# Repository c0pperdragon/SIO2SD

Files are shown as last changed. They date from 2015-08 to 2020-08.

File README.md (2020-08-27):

# SIO2SD
An Arduino-based floppy drive emulator for the Atari 8 bit computers.

This small Arduino build emulates an Atari 1050 floppy drive to connect
to an original Atari 8-bit computer. The program is compatible with
most Arduino boards. And for boards based on the Atmega32u4 it also provides
various log messages on the serial monitor to help debugging (mainly for my own use).

For a breadboard setup like my development device, you will need two push buttons,
two 7-digit LEDs and one SDCard socket (with built-in or separate level shifters) and
some wires and resistors. The connectivity is pretty standard and you will find
the details as comments in the source code.

For a more polished product, I have designed a PCB that can fit into a 3D-printed
case that resembles a tiny floppy drive with the SD card acting as a tiny floppy disk.

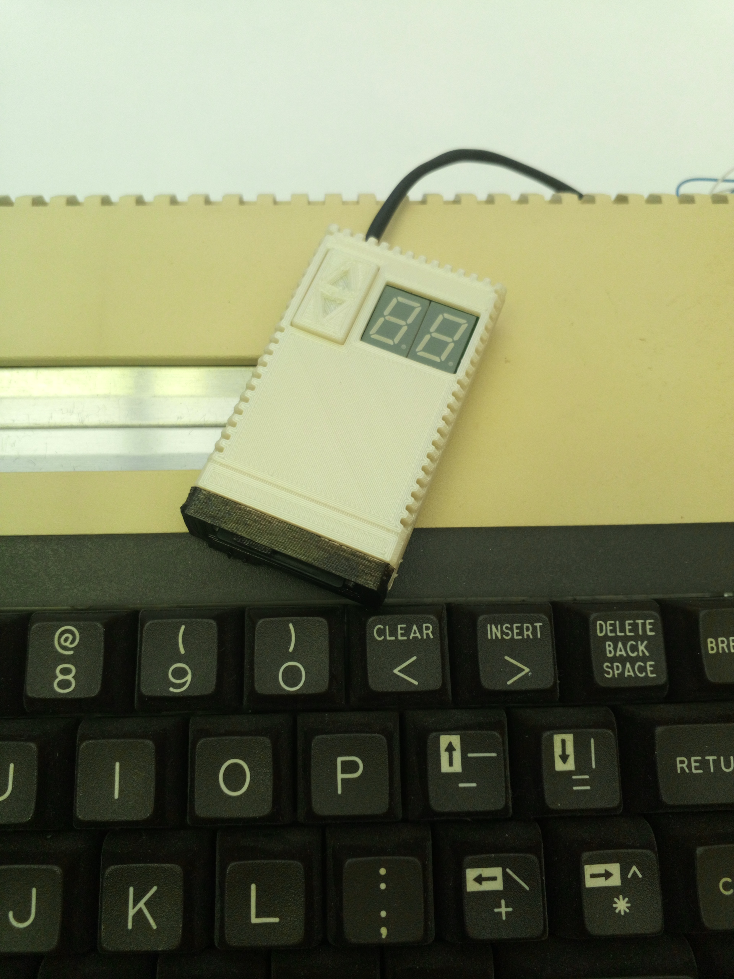
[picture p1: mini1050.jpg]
Big computer, small floppy drive


## Emulated floppies on SDcard
The floppy drive emulator needs an SDcard containing .ats files for each individual floppy disk.
Because there is no elaborated user-interface on the device, the naming and location of the files
need to follow a fixed system: The files are searched for in a directory ATARI/
on the root of the SDcard. Every disk file must be named nn_Anything.ats with two leading digits that correspond to the
numeric display on the device and the mandatory '_' character. Alternatively you can also
have a folder named nn_Anything with individual files inside. Such a folder will be emulated
as an read-only enhanced density floppy containing these files.

Currently only a very basic support for single density (720 sectors)
and enhanced density (1040 sectors) floppies is provided without special functions for any third-party devices.

## User interface
You can switch though the numbered disks 00 to 99 with the two buttons. This is the maximum number of disks 
supported on a single SDcard. When you switch beyond 99, you will see -- on the display, which means the device
now emulates a switched off floppy drive. Selecting a number for which no diskfile exists will simulate 
a device with no floppy inserted (in this case you can create a diskfile with the DOS format functions).

You can also emulate a second floppy drive, which is very usable for example for holding the save disks
for games that support this. To do so, you need to press both buttons to make the small indicator dot appear
on the left LCD block. This means that the number you see in the display is the floppy that is inserted
in drive 2. This floppy can now also be changed with the two buttons. It is even possible to select the same 
floppy in both drives at once (but this is probably of no great use).

## Latest hardware

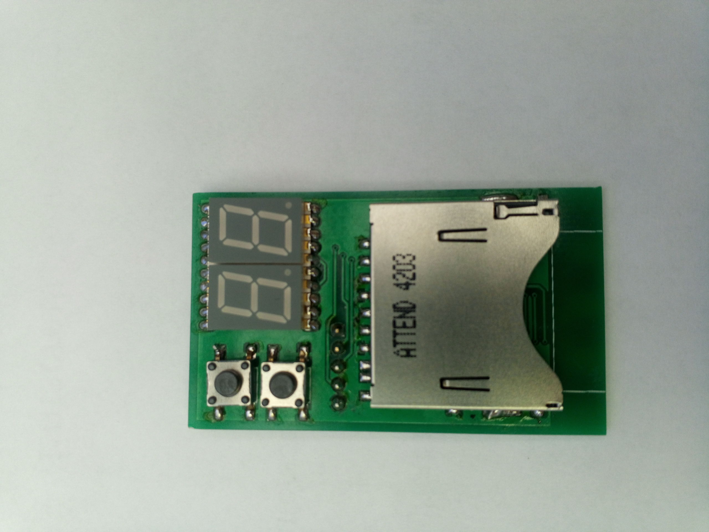
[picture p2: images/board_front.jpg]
Front side

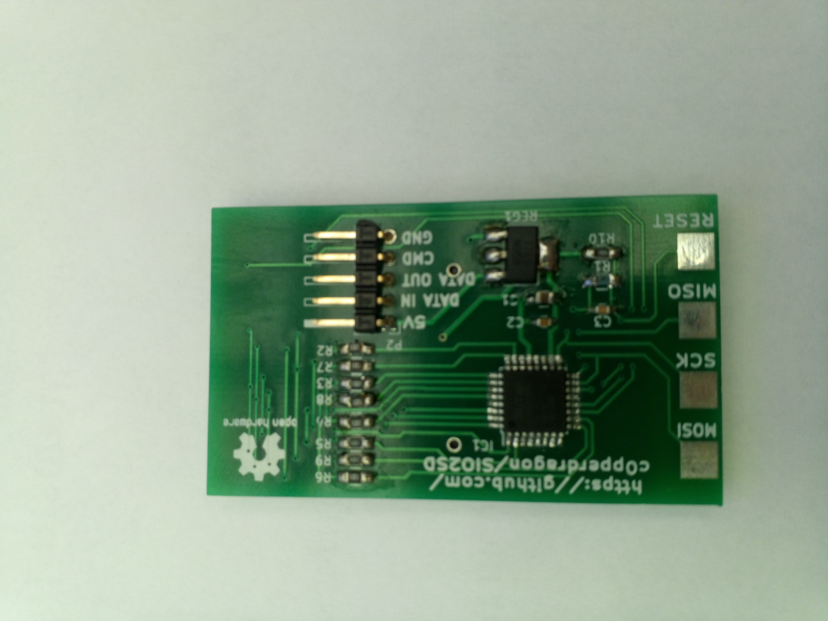
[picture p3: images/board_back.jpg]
Back side


## 3D-printed case

My brother went to greate lengths, designing a proper case for the floppy emulator. 
In my oppinion, this now looks absolutely phantastic.  

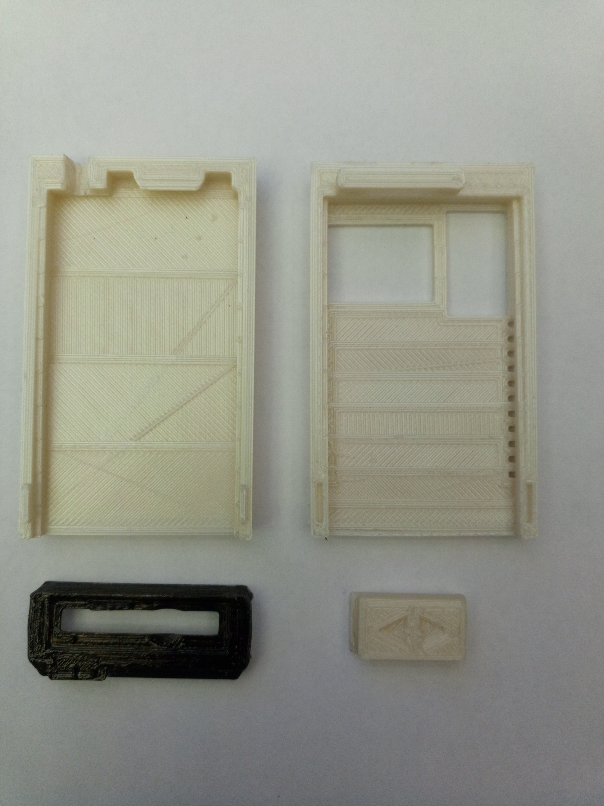
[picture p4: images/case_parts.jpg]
Individual parts of the case

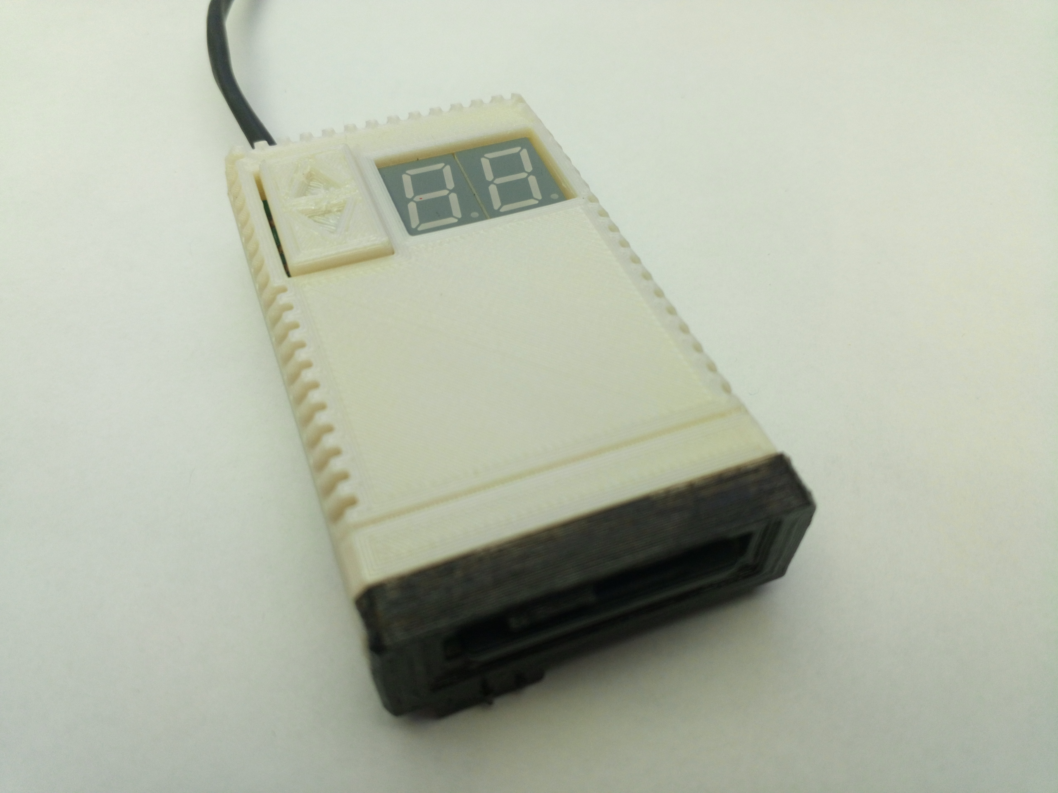
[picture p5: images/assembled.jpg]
Completely assembled


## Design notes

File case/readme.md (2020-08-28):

# Housing for an SD-Card version of the popular Atari-1050 floppy drive.

The case consists of 4 pieces and can be assembled without any screws.
It was modelled with blender, exported to STL files and sliced with cura.

The generated gcode is optimized for the anycubic i3-mega printer.

Layerheight is 0.2, first layer was 0.15 anyway because i wanted to avoid too much elephant foot, for otherwise the important design parts may be lost.

List of files:
* atari1050_sd_final.blend   - Blender file with the original Model data
* atari1050_sd_drive.gcode   - gcode for the 3d printer

* hull_top.stl, 
* hull_bottom.stl, 
* frontplate.stl, 
* buttons.stl                - STL-Files of the 4 Parts

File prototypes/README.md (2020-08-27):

# Prototype hardware variants

* First prototype with Arduino Micro. 
This was hand-wired. No longer supported by the firmware.

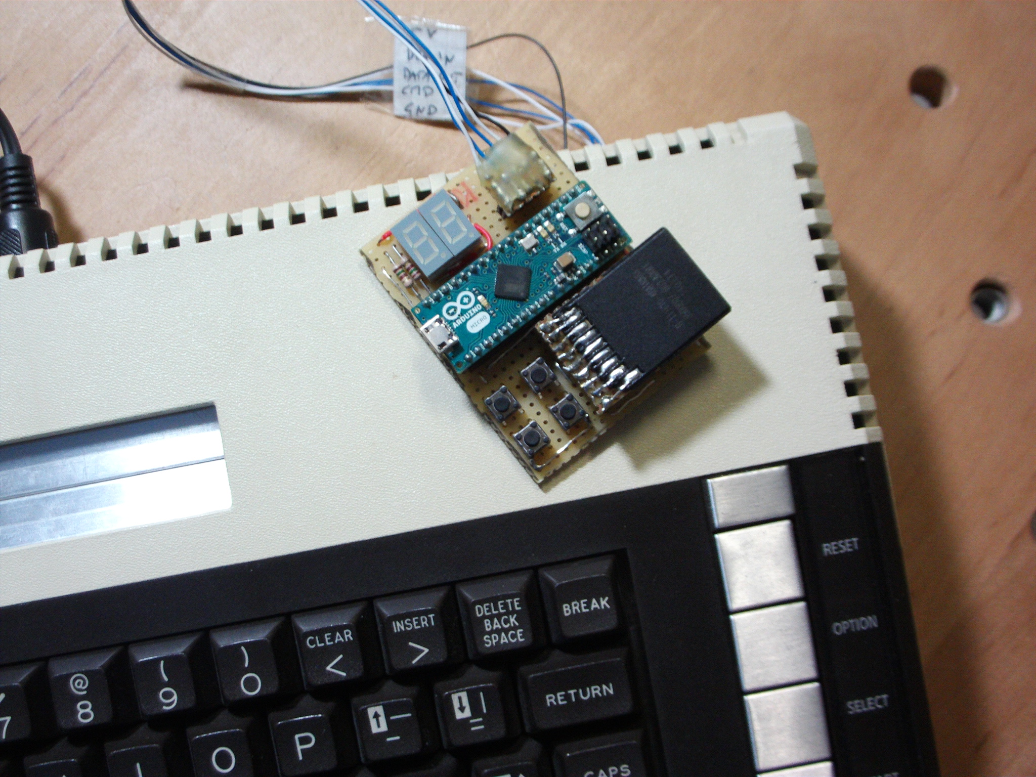
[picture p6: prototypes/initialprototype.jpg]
Initial Prototype


* Breadboard setup with Arduino Micro.
Because the MCU is running with 5V, I need level shifters to interface with the SDCard. This setup directly drives the 
Data-In line of the Atari without considering a multiple-slave configuration. This could be corrected with a simple schottky diode.
To keep the part count down, this setup only uses a single resistor per LED digit which causes varying brightness of the display segments.

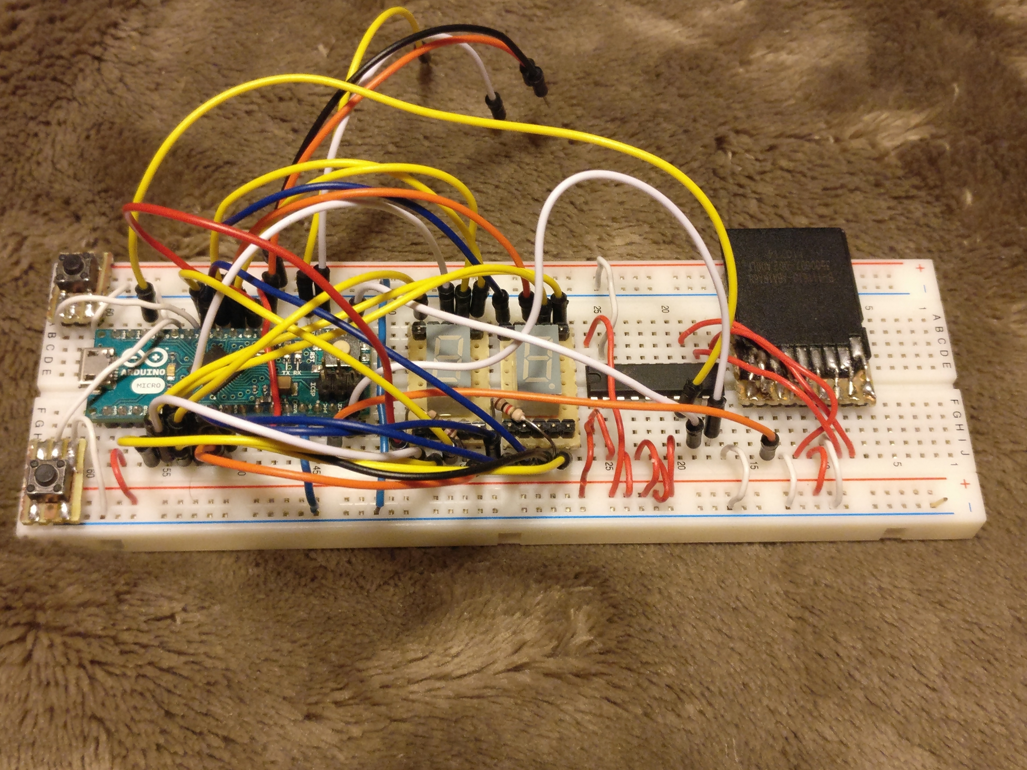
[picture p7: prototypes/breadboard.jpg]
Breadboard


* Bare bone ATmega328 (DIP package).
Designed to fit into a small form factor by using a home-etched two board design.
The MCU is running at 8MHz on 3.3V and can talk to SDCard without level shifters. The logic level difference between Atari and 
the MCU causes the incoming SIO high levels to be pulled down to about 3.9V by the internal clamp diodes. This only creates 
a small current (0.2mA) and should be OK as long as these lines are only driven by the pull-up resistors of the Atari.
The LEDs have resistors on the digit select lines only, therefore the brightness varies with the pattern.

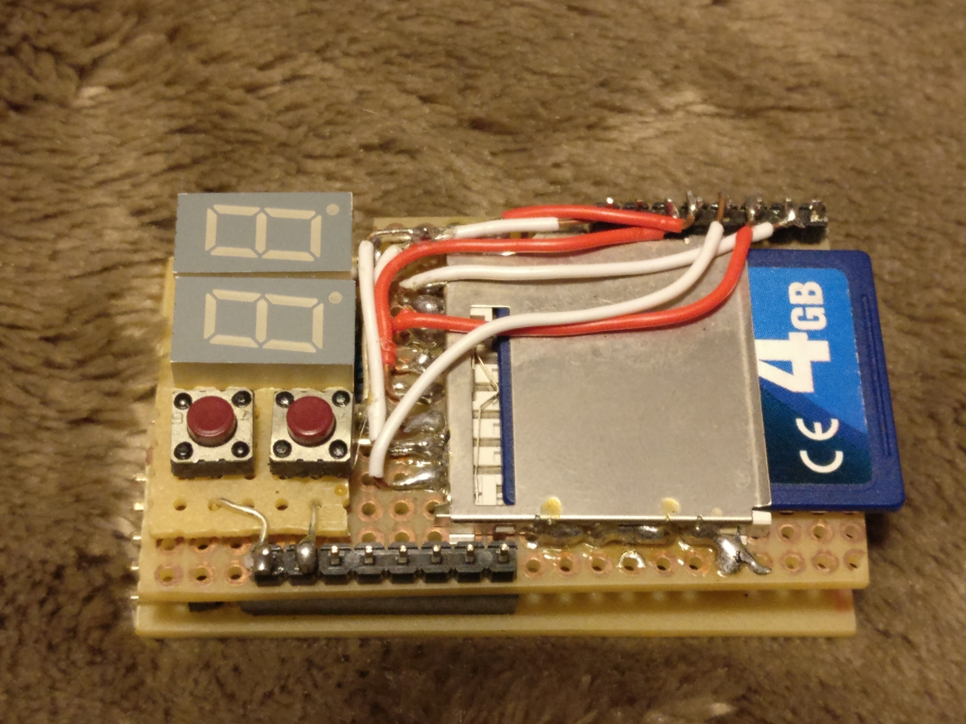
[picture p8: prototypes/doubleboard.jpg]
Double PCB layout


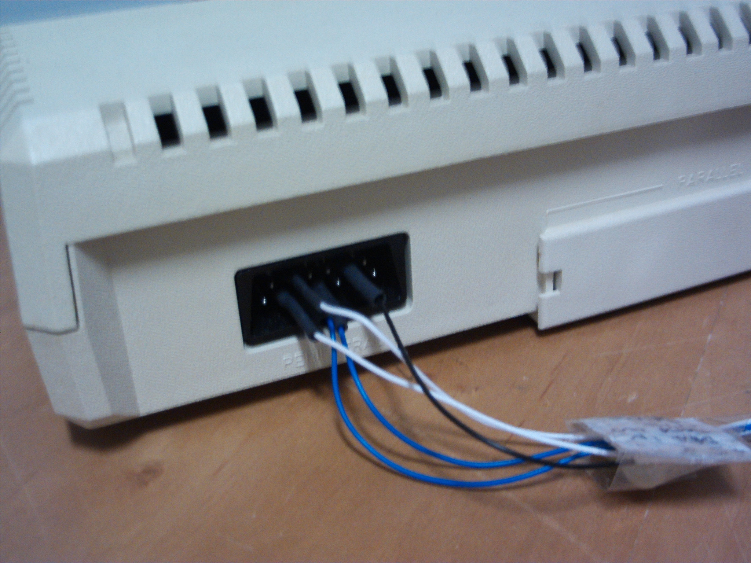
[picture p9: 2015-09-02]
doc/plugs.jpg

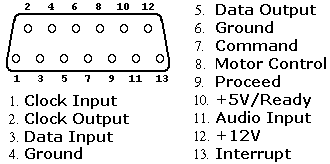
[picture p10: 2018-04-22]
doc/sio_socket.gif

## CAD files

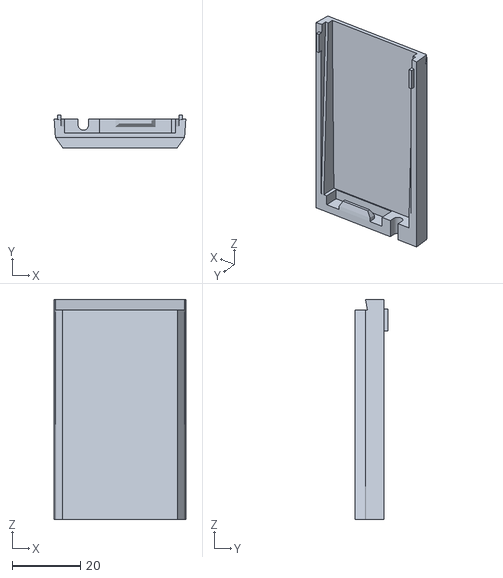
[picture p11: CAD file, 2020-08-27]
case/hull_bottom.stl
38.5 x 9.52 x 64.3

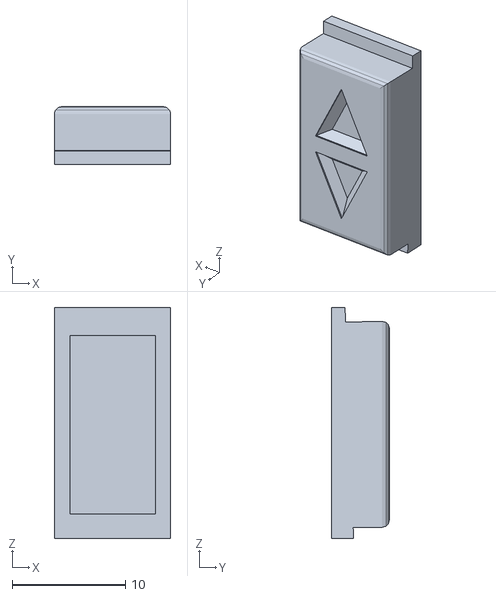
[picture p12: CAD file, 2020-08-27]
case/buttons.stl
10.3 x 5.13 x 20.4

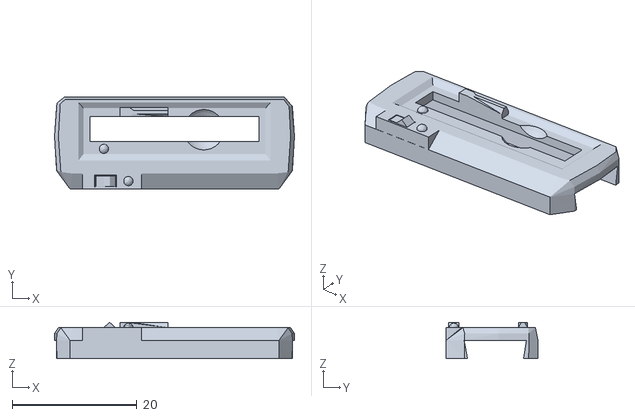
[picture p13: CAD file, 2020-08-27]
case/frontplate.stl
38.5 x 14.8 x 5.79

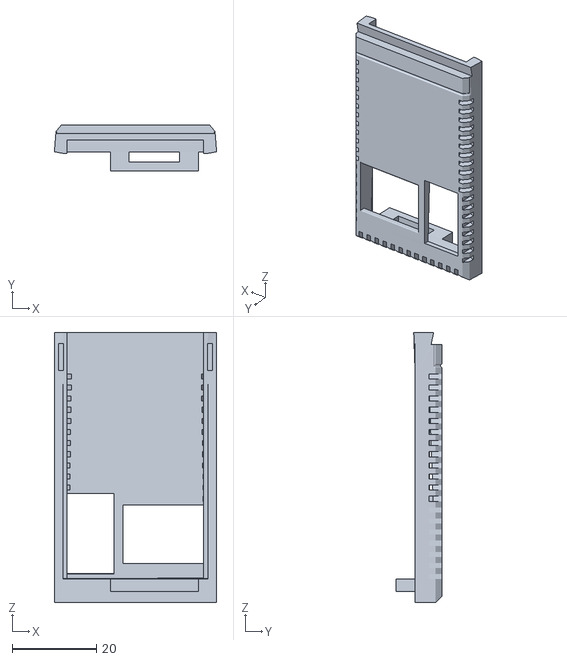
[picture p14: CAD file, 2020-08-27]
case/hull_top.stl
38.5 x 10.8 x 64.1

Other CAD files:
case/atari1050_sd_final.blend

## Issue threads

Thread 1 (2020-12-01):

No component type designation for D1

hanshuebner, 2020-12-01:
Thanks for making your SIO2SD available.  I built it and it looks gorgeous!

I have tried an 1N4148 for D1 as there is no type designation for it in the BOM, and the board does not react to commands on the SIO bus.  Does this diode need to be a Schottky diode?  If so, can you let me know what kind of diode works best?

Thanks!  Hans

c0pperdragon, 2020-12-01:
Yes, it needs to be a schottky diode with a forward voltage as low as possible. You may even shorten this connection when using the SIO2SD as the only device on the SIO bus (for test purposes). With multiple devices the diode is mandatory.

hanshuebner, 2020-12-01:
Thanks!  I'll try to find a suitable type, but if you could recommend one, it'd be greatly appreciated!  Cheers!

Closed 2020-12-01.

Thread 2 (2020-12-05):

Fuse bit settings not documented

hanshuebner, 2020-12-05:
Sorry to bother again:  Can you share the correct fuse bit settings for the device?

c0pperdragon, 2020-12-06:
I did not make special requirements in this regard to make the software work with any arduino compatible device.

When I designed my board, I could not get an Atmega328P, but only the slightly different Atmega328PB in the necessary package size. This gave me a bit of extra trouble because the chip ID is different and the flashing software did not work. I can not remember how I overcame this problem, but in the end it worked somehow.
By using the "normal" Atmega328P this should be easier as there is very good support in the arduino system for such bar-bones setups.
https://www.arduino.cc/en/Tutorial/BuiltInExamples/ArduinoToBreadboard
You need configure it to use the internal oscillator at 8Mhz.

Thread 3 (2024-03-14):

does it not run on normal Arduino Uno with 16MHz ?

mega-hz, 2024-03-14:
Hi,

is it right that this doesn't run on 16MHz?
If so, could you please correct the timers for running on staandart 16MHz?

c0pperdragon, 2024-03-14:
I don't think you need to change anything with the timings and run with 16MHz just fine. The timings are normally adjusted by the Arduino libraries accordingly.
8 MHz was just the highes speed available on a bare chip without external oscillator.

mega-hz, 2024-03-14:
ah, ok.
would it be possible to remove sd part and just listen to sio devices and commands?
Say, if D1 is reading, turn on a led, if writing, turn on another led....

c0pperdragon, 2024-03-14:
Brobably, but for this kind of bus-sniffing, the current code is a real overkill.
Maybe you want to do you own research on how to program such a thing from scratch. Here is a good resource for the protocol details:
https://www.atarimax.com/jindroush.atari.org/asio.html

mega-hz, 2024-03-14:
yes i know this site. just thought why do the whole work again. Your Sio Part should be run only, i will try.

mega-hz, 2024-03-14:
but stilll a nice project!
Even i prefere an display instead of 7Seg.

mega-hz, 2024-03-15:
i've got it running!
I only need your "handle-sio" routine.
If you don't mind i would like to use this in another Device.
SIO Device,Commands are shown on a LCD, works great!

c0pperdragon, 2024-03-15:
very nice.
and sure, use the code wherever you like

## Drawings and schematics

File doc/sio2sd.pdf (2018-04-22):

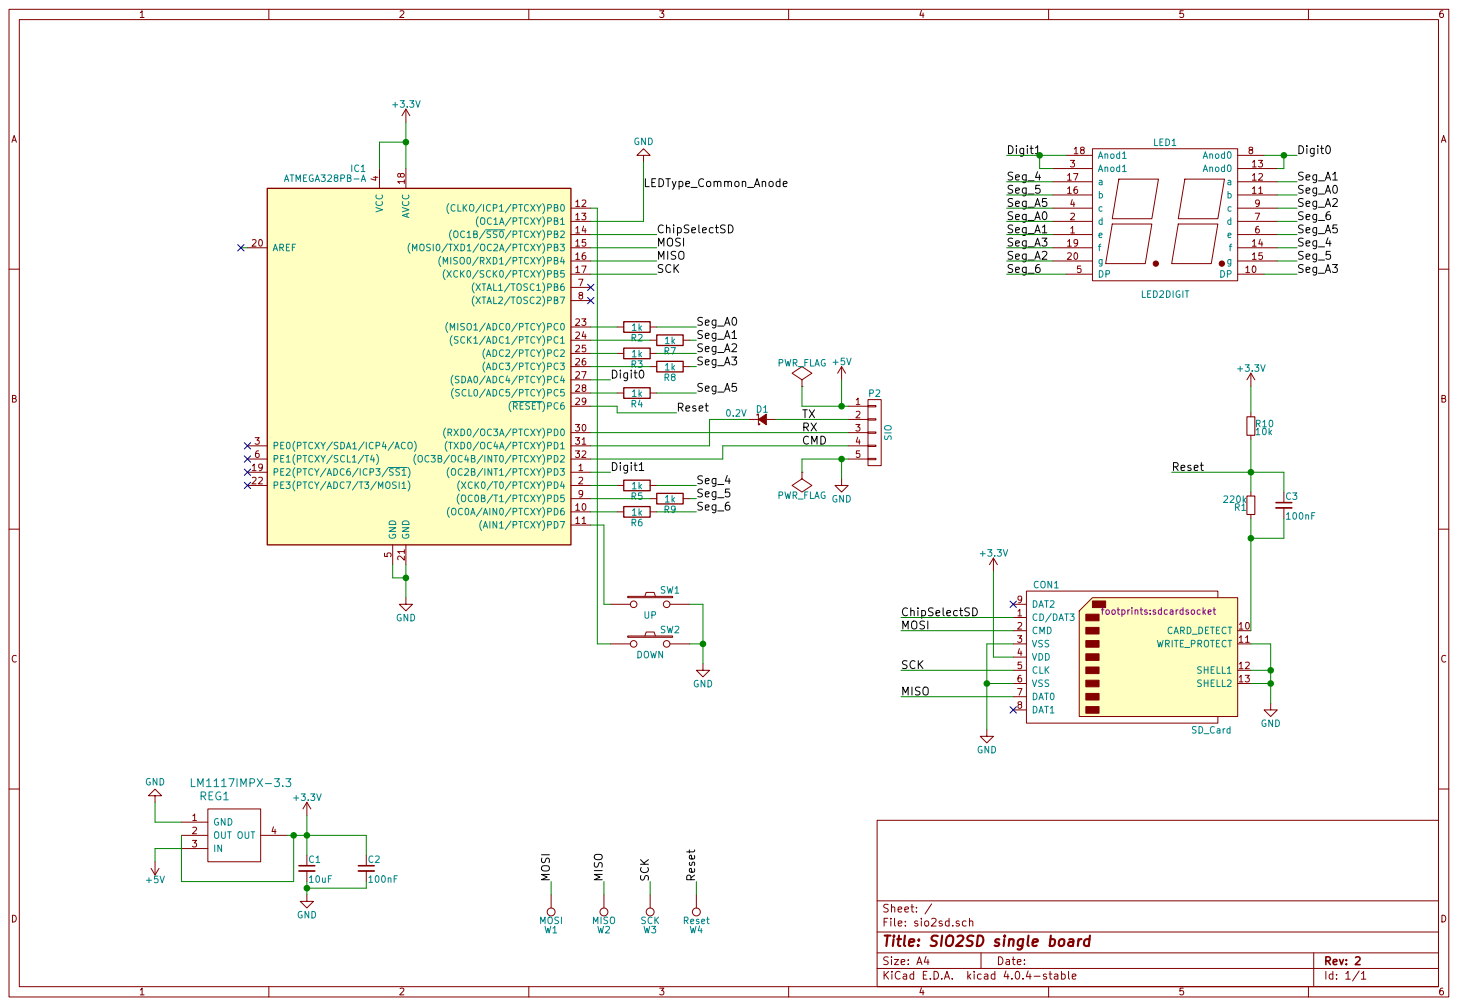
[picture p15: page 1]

File: sio2sd.sch Sheet: /
Id: 1/1 Title: SIO2SD single board

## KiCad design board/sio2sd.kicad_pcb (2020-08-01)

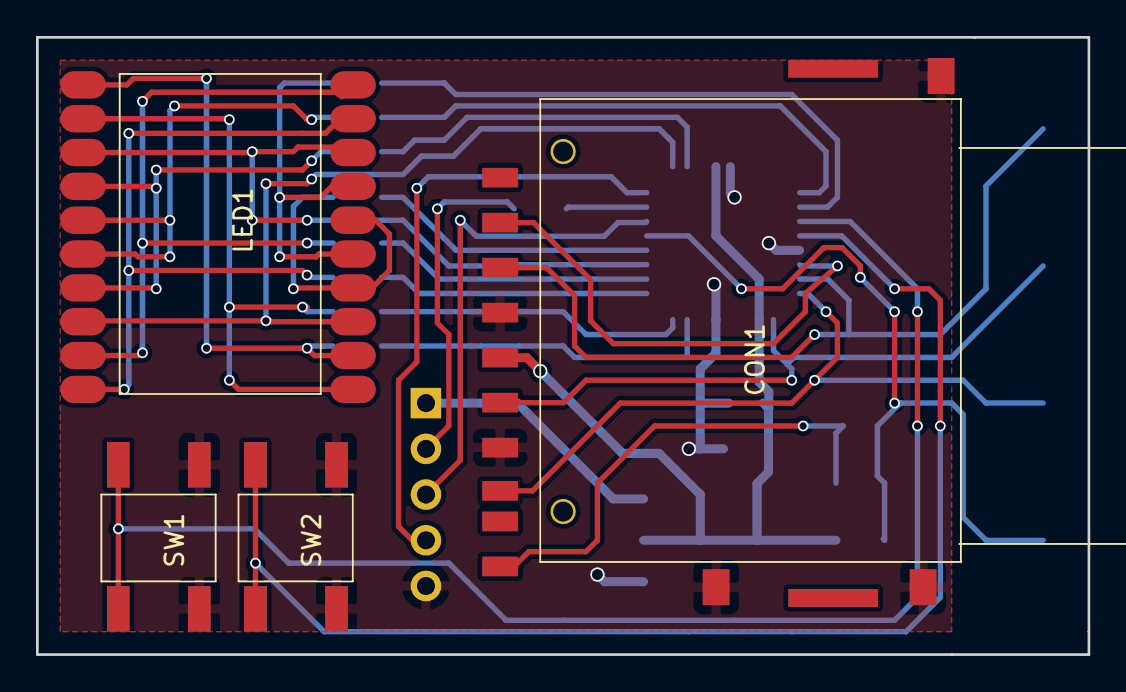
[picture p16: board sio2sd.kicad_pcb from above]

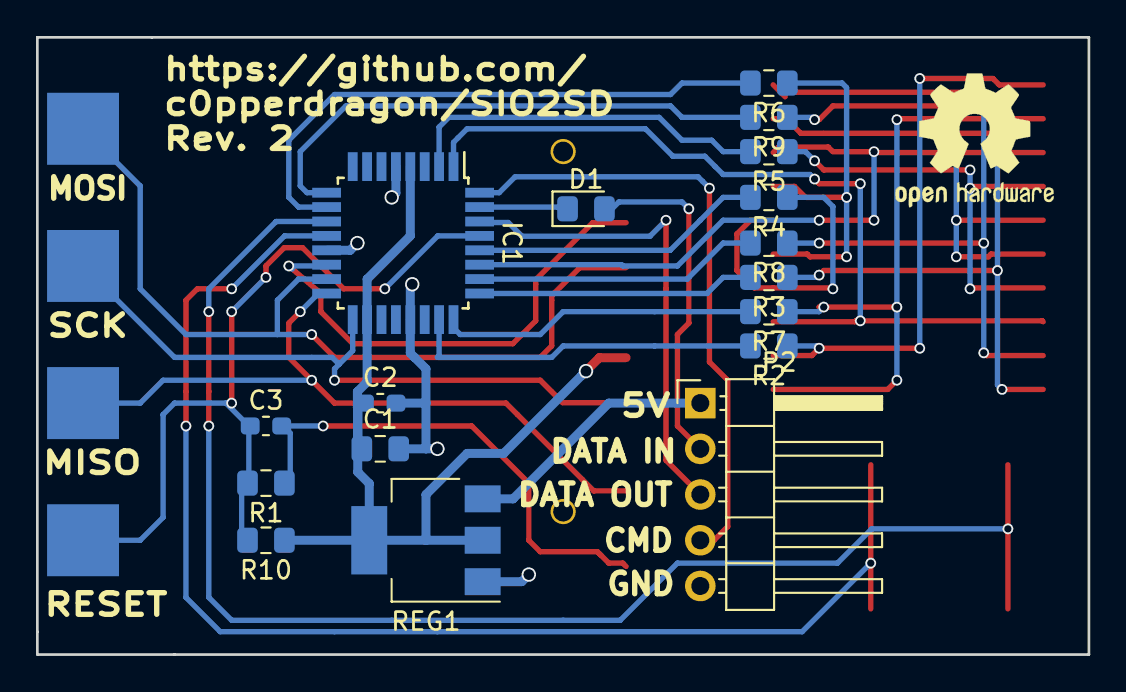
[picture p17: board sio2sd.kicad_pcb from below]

Board: 2 copper layers, 58.4 x 34.3 mm, 25 parts (21 on the bottom side), 33 nets.

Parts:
C1: 10uF; C_0805_2012Metric_Pad1.15x1.40mm_HandSolder
C2, C3: 100nF; C_0603_1608Metric_Pad1.05x0.95mm_HandSolder
CON1: SD_Card; sdcardsocket
D1: 0.2V; D_0805_2012Metric_Pad1.15x1.40mm_HandSolder
IC1: ATMEGA328PB-A; TQFP-32_7x7mm_P0.8mm
LED1: LED2DIGIT; led2digit
P2: SIO; PinHeader_1x05_P2.54mm_Horizontal
R1: 220k; R_0805_2012Metric_Pad1.15x1.40mm_HandSolder
R2, R3, R4, R5, R6, R7, R8, R9: 1k; R_0805_2012Metric_Pad1.15x1.40mm_HandSolder
R10: 10k; R_0805_2012Metric_Pad1.15x1.40mm_HandSolder
REG1: LM1117IMPX-3.3; SOT-223
SW1: UP; button
SW2: DOWN; button
W1: MOSI; pad
W2: MISO; pad
W3: SCK; pad
W4: Reset; pad

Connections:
+3V3: C1.1, C2.1, CON1.4, IC1.4, IC1.18, R10.1, REG1.2, REG1.4
+5V: P2.1, REG1.3
/CMD: IC1.32, P2.4
/ChipSelectSD: CON1.1, IC1.14
/Digit0: IC1.27, LED1.8, LED1.13
/Digit1: IC1.1, LED1.3, LED1.18
/MISO: CON1.7, IC1.16, W2.1
/MOSI: CON1.2, IC1.15, W1.1
/RX: IC1.30, P2.3
/Reset: C3.1, IC1.29, R1.2, R10.2, W4.1
/SCK: CON1.5, IC1.17, W3.1
/Seg_4: LED1.14, LED1.17, R5.1
/Seg_5: LED1.15, LED1.16, R9.1
/Seg_6: LED1.5, LED1.7, R6.1
/Seg_A0: LED1.2, LED1.11, R2.1
/Seg_A1: LED1.1, LED1.12, R7.1
/Seg_A2: LED1.9, LED1.20, R3.1
/Seg_A3: LED1.10, LED1.19, R8.1
/Seg_A5: LED1.4, LED1.6, R4.1
/TX: D1.2, P2.2
GND: C1.2, C2.2, CON1.3, CON1.6, CON1.11, CON1.12, CON1.13, IC1.5, IC1.13, IC1.21, P2.5, REG1.1, SW1.2, SW2.2
unnamed: C3.2, CON1.10, R1.1
unnamed: D1.1, IC1.31
unnamed: IC1.2, R5.2
unnamed: IC1.9, R9.2
unnamed: IC1.10, R6.2
unnamed: IC1.11, SW1.1
unnamed: IC1.12, SW2.1
unnamed: IC1.23, R2.2
unnamed: IC1.24, R7.2
unnamed: IC1.25, R3.2
unnamed: IC1.26, R8.2
unnamed: IC1.28, R4.2

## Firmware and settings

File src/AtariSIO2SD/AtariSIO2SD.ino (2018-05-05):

// --------- Program code for the IOS2SD Atari 1050 disk drive emulator -----------
// The program should be compatible with most arduino boards, as well
// as with a bare-bone atmega mcu.
// On boards with the ATmega32U4, logging via the usb uplink is enabled,
// while the the serial communication to the SIO interface 
// is routed over the dedicated serial pins. 

#include <SPI.h>
#include <SD.h>
#include <EEPROM.h>

// serial port RX/TX to Atari is either Serial or Serial1, d
// and if available, use USB line for logging
#if defined(__AVR_ATmega32U4__)
    #define SIO Serial1
    #define PRINT Serial.print
    #define PRINTLN Serial.println
    #define PRINTBEGIN Serial.begin
#else
    #define SIO Serial
    #define PRINT(...)        1
    #define PRINTLN(...)      1
    #define PRINTBEGIN(...)   1
//    #include <SoftwareSerial.h>
//    SoftwareSerial Logger(A7, 13); // RX, TX
//    #define PRINT Logger.print  // (...)        1
//    #define PRINTLN Logger.println   // (...)      1
//    #define PRINTBEGIN Logger.begin  // (...)   1
#endif

// ------------------------ the wiring up of all components ------------------------
// -- connection to Atari SIO port
                              // default arduino RX -> serial data from Atari SIO pin 5
                              // default arduino TX -> serial data to Atari SIO pin 3
#define PIN_SIOCOMMAND  2     //                    -> CMD signal from Atari SIO pin 7

// -- connection to SDCARD
                              // default MOSI
                              // default MSIO
                              // default SCK
#define PIN_CHIPSELECT  10    // enables SDCARD on SPI bus

// -- connection to LED display and mode selector
#define PIN_DIGIT0 A4         // enables LED digit 0 (right digit)
#define PIN_DIGIT1 3          // enables LED digit 1 (left digit)
// the digit segments are differently assigned for digit 0 and 1  
//           segment:    a   b   c   d   e   f   g   DP
byte pin_segments0[8] = {A1, A0, A2, 6,  A5, 4,  5,  A3}; 
byte pin_segments1[8] = {4,  5,  A5, A0, A1, A3, A2, 6};  
#define COMMON_ANODE_SELECTOR 9  // pull this input low to select common annode LED 

// -- connection to input buttons
#define PIN_BUTTON0  7      // up button   (connects to GND)
#define PIN_BUTTON1  8      // down button (connects to GND)


// ------------------ DISK SELECTOR (LED DIGITS AND BUTTONS) -----------
// because the two digits are displayed in a multiplexted fashion (to reduce number of needed pins),
// they will be displayed alternately. a timer interrupt  comes handy to do this.

volatile byte selecteddisk[2];
volatile int activitylight[2];
#define ACTIVITY_LIGHT_DURATION 10

byte activedigit; 
byte showndiskdrive;
int valuesavedelay;

byte prevbuttonstate;
byte timesincebuttonchange;
bool inputlock;
bool showerror;

// various digits             gfedcba
byte digitpatterns[13] = 
{   B00111111,   // 0
    B00000110,   // 1
    B01011011,   // 2
    B01001111,   // 3
    B01100110,   // 4
    B01101101,   // 5
    B01111101,   // 6
    B00000111,   // 7
    B01111111,   // 8
    B01101111,   // 9
    B01000000,   // -
    B01111001,   // E
    B01010000,   // r
};

#define TIMERFREQUENCY ((F_CPU/2)/256)      // timer frequency after prescaling of 256 (in Hz)
#define TIMERCYCLES  (TIMERFREQUENCY/200)   // this many timer ticks to get a 200Hz interrupt period
#define TIMERRESETVALUE (65536-TIMERCYCLES) // set counter to overflow in given time

void initdiskselector()
{
    byte i;

    // init input buttons
    pinMode(PIN_BUTTON0, INPUT_PULLUP);
    pinMode(PIN_BUTTON1, INPUT_PULLUP);
    pinMode(COMMON_ANODE_SELECTOR, INPUT_PULLUP);
    
    // read selector values at startup
    selecteddisk[0] = read_eeprom(0);
    selecteddisk[1] = read_eeprom(1);
  
    // init various UI flags
    activitylight[0] = 0;
    activitylight[1] = 0;
    activedigit = 0;
    showndiskdrive = 0;
    valuesavedelay = 0;
    prevbuttonstate = 0;
    timesincebuttonchange = 0;
    inputlock = false;
  
    // configure and turn of digit selectors 
    pinMode(PIN_DIGIT0, OUTPUT);
    digitalWrite (PIN_DIGIT0, LOW);
    pinMode(PIN_DIGIT1, OUTPUT);
    digitalWrite (PIN_DIGIT1, LOW);  
    // configure and turn off individual digits
    for (i=0; i<8; i++)
    {   pinMode(pin_segments0[i], OUTPUT);
        digitalWrite (pin_segments0[i], LOW);
        pinMode(pin_segments1[i], OUTPUT);
        digitalWrite (pin_segments1[i], LOW);
    }  

    // start timer
    noInterrupts();  
    TCCR1A = 0;
    TCCR1B = 0;
    TCNT1 = TIMERRESETVALUE;  // Timer nach obiger Rechnung vorbelegen
    TCCR1B |= (1 << CS12);    // 256 als Prescale-Wert spezifizieren
    TIMSK1 |= (1 << TOIE1);   // Timer Overflow Interrupt aktivieren
    interrupts();              // alle Interrupts scharf schalten
}


// interrupt service routine is called 200 times per second 
// (must not take much time)
// this handles user input and also drives the LED digits
ISR(TIMER1_OVF_vect)        
{
  TCNT1 = TIMERRESETVALUE; 
  polldiskselector();
}
void polldiskselector()   
{
    // poll buttons only 100 times per second to reduce bumping
    if (activedigit==0 && !showerror) 
    {   byte buttonstate = 0;
    
        // --- query current button states and detect changes ---
        if (digitalRead(PIN_BUTTON0)==LOW) { buttonstate =  buttonstate | 1; }
        if (digitalRead(PIN_BUTTON1)==LOW) { buttonstate =  buttonstate | 2; }
    
        // -- detect a press of both buttons: switch shown disk drive 
        if ((buttonstate&3)==3 && (prevbuttonstate&3)!=3 && !inputlock)
        {   showndiskdrive = 1-showndiskdrive;
            inputlock = true;
        }
        if (prevbuttonstate==0 && buttonstate==0) { inputlock=false; }
    
        // -- detect clicks of single up and down buttons and provide key repeat function
        if (!inputlock)
        {   if ( ((buttonstate&1)==0 && (prevbuttonstate&1)!=0) || ((buttonstate&1)!=0 && timesincebuttonchange>=100) ) 
            {   selecteddisk[showndiskdrive] ++;
                if (selecteddisk[showndiskdrive]>100) selecteddisk[showndiskdrive]=0;  
                valuesavedelay = 100;    
            }
            if ( ((buttonstate&2)==0 && (prevbuttonstate&2)!=0) || ((buttonstate&2)!=0 && timesincebuttonchange>=100) ) 
            {   selecteddisk[showndiskdrive] --;
                if (selecteddisk[showndiskdrive]>100) selecteddisk[showndiskdrive]=100;      
                valuesavedelay = 100;    
            }
        }    
    
        // -- memorize current button state for next poll to then detect edges
        if (buttonstate!=prevbuttonstate)
        {   prevbuttonstate = buttonstate;
            timesincebuttonchange=0;
        }          
        else
        {   if (timesincebuttonchange<100) { timesincebuttonchange++; }
            else                           { timesincebuttonchange-=5; }
        }
        
        // --- handling of delay before saving the current selected value
        if (valuesavedelay>0 && buttonstate==0)
        {   valuesavedelay --;
            if (valuesavedelay==0)
            {   store_eeprom(0, selecteddisk[0]);
                store_eeprom(1, selecteddisk[1]);
            }
        }
    }
    

    // --- count down activity light duration
    if (activitylight[0]>0) {   activitylight[0]--;  }
    if (activitylight[1]>0) {   activitylight[1]--;  }
  
    // --- display digits alternatingly ----
    // switch to other digit
    activedigit = 1-activedigit;

    // determine if need to drive a common cathode or common anode LED
    byte commoncathode = digitalRead(COMMON_ANODE_SELECTOR);
  
    // turn on/off digit segments as needed (pin assignment is quite arbitrary)
    if (activedigit==0) 
    {   byte value = selecteddisk[showndiskdrive];
        value = showerror ? 12 : ((value<=99) ? (value % 10) : 10);   // when drive is off: - 
        digitalWrite (PIN_DIGIT1, commoncathode ? HIGH : LOW);  // turn off digit 1
        byte i;
        byte v = digitpatterns[value];
        for (i=0; i<7; i++) 
        {   if (v&(1<<i)) { digitalWrite (pin_segments0[i], commoncathode ? HIGH : LOW); }
            else          { digitalWrite (pin_segments0[i], commoncathode ? LOW : HIGH); }
        }
        // this dot is used to see if drive 0 is visible and if activity on disk 0
        bool dot = showndiskdrive==0 && !showerror;
        if (activitylight[0]>0) { dot = !dot; }
        if (dot) { digitalWrite (pin_segments0[7], commoncathode ? HIGH : LOW); }
        else     { digitalWrite (pin_segments0[7], commoncathode ? LOW : HIGH); }
        digitalWrite (PIN_DIGIT0, commoncathode ? LOW : HIGH);  // turn on digit 0
    }
    else 
    {   byte value = selecteddisk[showndiskdrive];
        value = showerror ? 11 : ((value<=99) ? (value / 10) : 10);   // when drive is off: -
        digitalWrite (PIN_DIGIT0, commoncathode ? HIGH  : LOW);   // turn off digit 0
        byte i;
        byte v = digitpatterns[value];
        for (i=0; i<7; i++) 
        {   if (v&(1<<i)) { digitalWrite (pin_segments1[i], commoncathode ? HIGH : LOW); }
            else          { digitalWrite (pin_segments1[i], commoncathode ? LOW : HIGH); }
        }
        // this dot is used to see if drive 1 is visible and if activity on disk 1
        bool dot = showndiskdrive==1 && !showerror;
        if (activitylight[1]>0) { dot = !dot; }
        if (dot) { digitalWrite (pin_segments1[7], commoncathode ? HIGH : LOW); } 
        else     { digitalWrite (pin_segments1[7], commoncathode ? LOW : HIGH); } 
        digitalWrite (PIN_DIGIT1, commoncathode ? LOW : HIGH);  // turn on digit 1
    }  
}

// ------------------ EEPROM storage with wear-levelling -----------
// To prevent frequent writing to a single EEPROM cell to wear out this particual storage,
// the writes are distributed over a wide range of the available EEPROM. This is
// possible because only a very tiny amount of data needs to be stored int each slot
// (a 7-bit value).
// It works as follows: A splot consists of 256 bytes EEPROM storage. The one active
// data value (7 bits) can be found on the first byte position that has a different most significant
// bit (MSB) value than all previous bytes. In the case that all bytes in the slot have the
// same MSB, the very first byte is taken.
// Writing a new value into the slot will be done by overwriting the byte just before
// the previous value-carrying byte with the proper MSB set. 
// By this only one byte is overwritten in each write operation and it will always be a
// different one in the slot.

byte read_eeprom(byte slot)
{
    // find the first different MSB and take the value from there
    int start = ((int)slot) * 256;
    byte b0 = EEPROM.read(start);
    int i;
    for (i=start+1; i<start+256; i++)
    {   byte b1 = EEPROM.read(i);
        if ( (b0&0x80) != (b1&0x80)) { return b1 & 0x7f; }
        b0 = b1;
    }
    return EEPROM.read(start) & 0x7f;
}

void store_eeprom(byte slot, byte value)
{
    // make sure to not store unnecessarily 
    if (read_eeprom(slot)==value) { return; }

    // find the first different MSB 
    int start = ((int)slot) * 256;
    byte b0 = EEPROM.read(start);
    int i;
    for (i=start+1; i<start+256; i++)
    {   byte b1 = EEPROM.read(i);
        // if found a different MSB, store the value just in the place before
        if ( (b0&0x80) != (b1&0x80)) 
        {   EEPROM.write(i-1, (value&0x7f) | (b1&0x80));
            PRINT(F("Stored "));
            PRINT(value);
            PRINT(F(" to EEPROM byte "));
            PRINTLN(i-1);
            // when having written to location 0 make sure to have no other MSB edges 
            if (i==1) { cleanmsb_eeprom(slot); }
            return;
        }
        b0 = b1;
    }
    // if no suitable place could be found (all MSB equal, start at the end)
    EEPROM.write(start+255, (value&0x7f) | ((~b0)&0x80)); 
}

void cleanmsb_eeprom(byte slot)
{
    int start = ((int)slot) * 256;
    byte b0 = EEPROM.read(start);
    int i;
    for (i=start+1; i<start+256; i++)
    {   byte b1 = EEPROM.read(i);
        if ( (b0&0x80)!=(b1&0x80) )
        {   EEPROM.write(i, (b0&0x80)|(b1&0x7f)); 
            PRINT(F("Cleaned EEPROM byte "));
            PRINTLN(i);            
        }
    }
}



// ---------------------- DISK FILE HANDLING  -----------------------

boolean isinitsd = false;

File diskfile;                 // can be a .ATR file or a directory
unsigned int disksize;         // size in sectors

File atarifile;                // currently used file of a directory (if used in this mode)
unsigned int firstfilesector;  // first sector (numbered in "usable sectors) of the file
byte directoryindexoffile;     // to which directory entry the current file belongs


void opendiskfile(int index)
{  
    // check if desired file is already open - continue to use it
    if (diskfile && isrequesteddiskfile(diskfile,index)) { return; } 
  
    // before switching disk file, close any previous open
    if (diskfile) { diskfile.close(); }
    if (atarifile) { atarifile.close(); }

    // if not done already try to initialize the SDcard - on failure can not resume
    if (!isinitsd)
    {
        pinMode(PIN_CHIPSELECT,OUTPUT);
        digitalWrite(PIN_CHIPSELECT,HIGH);
        if (!SD.begin(PIN_CHIPSELECT)) 
        {   PRINTLN(F("SDCard failed, or not present"));
            return;
            showerror = true;
        }      
        isinitsd = true;
    }
  
    // try to scan the files in the ATARI directory on the SDCARD and 
    // locate the file name beginning with the correct index (2 digits).
    char fullname[60];
    fullname[0] = '\0';
  
    File root = SD.open(F("ATARI"));
    if (!root || !root.isDirectory())
    {   PRINTLN(F("Can not locate ATARI/ directory"));      
        return;             
    }  
    while (fullname[0]=='\0')
    {   File entry = root.openNextFile();
        if (!entry)
        {   PRINT(F("Could not find file for disk "));
            PRINTLN(index);
            root.close();
            return;
        }
        // check if name matches
        if (isrequesteddiskfile(entry,index))
        { // fill data into the fullname variable (which terminates the loop)
            strcat (fullname, "ATARI/");
            strcat (fullname, entry.name());
        }
        entry.close();
    }      
    root.close();
  
    // try to open the file in read-write mode, and if this does not
    // succeed in read-only mode
    PRINT(F("Trying to open "));
    PRINTLN(fullname);      

    bool readonly = false;
    diskfile = SD.open(fullname, FILE_WRITE);
    if (diskfile)
    {   diskfile.seek(0);
    }
    else
    {   diskfile = SD.open(fullname, FILE_READ);
        readonly = true;
    }  
    // abort if not possible to open
    if (!diskfile)
    {   PRINT(F("Can not open disk file"));
        PRINTLN(fullname);
        return;
    }       
    
    // check if the file is a directory instead of a diskfile 
    if (diskfile.isDirectory())
    {   PRINT(F("Using directory content to emulate a 1040 sector floppy: "));
        PRINTLN(fullname);
        disksize = 1040;
        return;
    }
    
    // read the header
    byte header[16];
    int didread = diskfile.read(header,16);
    if (didread!=16)
    {   PRINTLN(F("Can not read file header"));
        diskfile.close();
        return;
    }
    // check for signature and other settings
    if (header[0]!=0x96 || header[1]!=0x02)
    {   PRINTLN(F("Magic number not present"));
        diskfile.close();
        return;
    }
    if (header[5]!=0 or header[4]!=128)
    {   PRINTLN(F("Can only handle 128 byte sectors"));
        diskfile.close();     
        return;
     }

    unsigned long paragraphs = header[6];
    paragraphs = (paragraphs<<8) | header[3];
    paragraphs = (paragraphs<<8) | header[2];
    if (paragraphs<8 || paragraphs>0x70000)
    {   PRINTLN(F("Disk file size out of range."));
        diskfile.close();
        return;
    }
  
    // seems to be a valid diskfile - use it
    disksize = (paragraphs) >> 3;
    
    PRINT(F("SIZE: "));
    PRINT(disksize);
    PRINT(F(" sectors of 128 bytes"));
    if (readonly) { PRINTLN(F(" (read only)")); }
    else          { PRINTLN(F(" (writeable)")); }
}

bool isrequesteddiskfile(File f, int index)
{
    char* n = f.name();
    if (n[0]>='0' && n[0]<='9' && n[1]>='0' && n[1]<='9' && ((n[0]-'0')*10 + n[1]-'0')==index && n[2]=='_')
    {   return true; 
    }
    return false;
}

bool readsector(unsigned int sector, byte* data)
{   
    if (!diskfile || sector<1 || sector>disksize) { return false; }
    if (diskfile.isDirectory()) 
    {   if (!readsectorfromdirectory(sector,data)) { return false; }
        return true;
    }    
    if (!diskfile.seek(16+((unsigned long)(sector-1))*128) ) { return false; }
    return diskfile.read(data, 128) == 128;
}

bool writesector(unsigned int sector, byte* data)
{
    if (!diskfile || diskfile.isDirectory() || sector<1 || sector>disksize) { return false; }
    if (!diskfile.seek(16+((unsigned long)(sector-1))*128)) { return false; }
    return diskfile.write(data, 128) == 128;
}

bool diskavailable()
{
    if (diskfile) { return true; }
    else          { return false; }
}

bool creatediskfile(int index, int sectors)
{
    char fullname[101];
    fullname[0] = 0;
    strcat (fullname, "ATARI/");    
    
    opendiskfile(index);    
    // if possible reuse the already available disk file name (and remove old file first)
    if (diskfile)
    {   if (diskfile.isDirectory()) 
        {   PRINTLN(F("Can not format directory"));
            return false;
        }
        strcat (fullname, diskfile.name());
        diskfile.close();
        if (!SD.remove(fullname)) {
            PRINT(F("Can not remove old disk file "));
            PRINTLN(fullname);
            return false;
        }
    }
    // otherwise invent a new disk file name
    else
    {   strcat(fullname, "00_disk.atr");
        fullname[6] = '0' + (index / 10);
        fullname[7] = '0' + (index % 10);
    }

    PRINT(F("Creating disk file "));
    PRINT(fullname);
    PRINT(F(" with "));
    PRINT(sectors);
    PRINTLN(F(" sectors"));
    diskfile = SD.open(fullname, FILE_WRITE);
    if (!diskfile) { return false; }
    
    byte chunk[16];
    // construct header: magic number
    chunk[0] = (byte) 0x96;
    chunk[1] = (byte) 0x02;
    // paragraphs
    int paragraphs = sectors * 8; 
    chunk[2] = (byte) (paragraphs & 0xff);
    chunk[3] = (byte) ((paragraphs>>8) & 0xff);
    // sector size
    chunk[4] = (byte)128;
    chunk[5] = (byte)0;
    // 10 byte unused
    int i=0;
    for (i=6; i<16; i++) { chunk[i] = 0; }
    diskfile.write(chunk, 16);
    
    // create rest of file
    for (i=0; i<16; i++) { chunk[i] = 0x00; }
    for (i=0; i<paragraphs; i++)
    {   diskfile.write(chunk, 16);
    }

    diskfile.close();
    PRINTLN(F("Finished creating disk file"));
    return true;
}

const byte bootblocks[] PROGMEM = {
    0x00,0x03,0x00,0x07,0x40,0x15,0x4c,0x14,0x07,0x03,0x83,0x00,0xcc,0x19,0x01,0x04,
    0x00,0x7d,0xcb,0x07,0xac,0x0e,0x07,0xf0,0x35,0x20,0x5f,0x07,0xad,0x10,0x07,0xac,
    0x0f,0x07,0xa6,0x24,0x8e,0x04,0x03,0xa6,0x25,0x8e,0x05,0x03,0x18,0x20,0x6c,0x07,
    0x30,0x1c,0xac,0x11,0x07,0xb1,0x24,0x29,0x03,0xaa,0xc8,0x11,0x24,0xf0,0x11,0xb1,
    0x24,0x48,0xc8,0xb1,0x24,0x20,0x55,0x07,0x68,0xa8,0x8a,0x4c,0x22,0x07,0xa9,0xc0,
    0x0a,0xa8,0x60,0xa9,0x80,0x18,0x65,0x24,0x85,0x24,0x90,0x02,0xe6,0x25,0x60,0xad,
    0x12,0x07,0x85,0x24,0xad,0x13,0x07,0x85,0x25,0x60,0x00,0x00,0x8d,0x0b,0x03,0x8c,
    0x0a,0x03,0xa9,0x52,0xa0,0x40,0x90,0x04,0xa9,0x57,0xa0,0x80,0x08,0xa6,0x21,0xe0,
    0x08,0xd0,0x07,0x28,0x20,0x81,0x14,0x4c,0xb9,0x07,0x28,0x8d,0x02,0x03,0xa9,0x0f,
    0x8d,0x06,0x03,0x8c,0x17,0x13,0xa9,0x31,0x8d,0x00,0x03,0xa9,0x03,0x8d,0x09,0x13,
    0xa9,0x80,0x8d,0x08,0x03,0x0a,0x8d,0x09,0x03,0xad,0x17,0x13,0x8d,0x03,0x03,0x20,
    0x59,0xe4,0x10,0x05,0xce,0x09,0x13,0x10,0xf0,0xa6,0x49,0x98,0x60,0x20,0xad,0x11,
    0x20,0x64,0x0f,0x20,0x04,0x0d,0x4c,0xc7,0x12,0x00,0x00,0x64,0x08,0x8f,0x0a,0x4d,
    0x0a,0x8f,0x09,0xbc,0x07,0x2a,0x0b,0x80,0x40,0x20,0x10,0x08,0x04,0x02,0x01,0xff,
    0xad,0x0c,0x07,0x85,0x24,0xad,0x0d,0x07,0x85,0x25,0xad,0x0a,0x07,0x85,0x43,0xa2,
    0x07,0xa9,0x00,0x06,0x43,0x90,0x15,0xa0,0x05,0x91,0x24,0xa5,0x24,0x9d,0x29,0x13,
    0xa5,0x25,0x9d,0x31,0x13,0xa9,0x90,0x20,0x55,0x07,0xa9,0x64,0x9d,0x19,0x13,0xca,
    0x10,0xdf,0xa5,0x24,0x8d,0x39,0x13,0xa5,0x25,0x8d,0x3a,0x13,0xac,0x09,0x07,0xa2,
    0x00,0x88,0x98,0x9d,0x21,0x13,0x30,0x03,0x20,0x53,0x07,0xe8,0xe0,0x08,0xd0,0xf1,
    0xa5,0x24,0x8d,0xe7,0x02,0xa5,0x25,0x8d,0xe8,0x02,0xa9,0x00,0xa8,0x99,0x81,0x13,
    0xc8,0x10,0xfa,0xa8,0xb9,0x1a,0x03,0xf0,0x0c,0xc9,0x44,0xf0,0x08,0xc8,0xc8,0xc8,
    0xc0,0x1e,0xd0,0xf0,0x00,0xa9,0x44,0x99,0x1a,0x03,0xa9,0xcb,0x99,0x1b,0x03,0xa9,
    0x07,0x99,0x1c,0x03,0x60,0x20,0xad,0x11,0x20,0x7d,0x0e,0xbd,0x4a,0x03,0x9d,0x82,
    0x13,0x29,0x02,0xf0,0x03,0x4c,0x72,0x0d,0x20,0xec,0x0e,0x08,0xbd,0x82,0x13,0xc9      
};
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
void loop()
{
    handle_sio();
}

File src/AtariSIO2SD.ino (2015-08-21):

#include <SPI.h>
#include <SD.h>
#include <TimerOne.h>

#define PIN_CHIPSELECT  13
#define PIN_SIOCOMMAND  2


// ------------------ DISC SELECTOR (LED DIGITS AND BUTTONS) -----------
// because the two digits are displayed in a multiplexted fasion (to reduce number of needed pins),
// they will be displayed alternately. a timer interrupt  comes handy to do this.

byte prevbuttonstate[4];

volatile byte digit0value;  
volatile byte digit1value;  
volatile int activitylight;
byte activedigit; 

// various digits                0      1      2      3      4      5      6      7      8     9
bool segment_top[10]         = { true,  false, true,  true,  false, true,  true,  true,  true, true  };
bool segment_middle[10]      = { false, false, true,  true,  true,  true,  true,  false, true, true  };
bool segment_bottom[10]      = { true,  false, true,  true,  false, true,  true,  false, true, true  };
bool segment_lefttop[10]     = { true,  false, false, false, true,  true,  true,  false, true, true  };
bool segment_leftbottom[10]  = { true,  false, true,  false, false, false, true,  false, true, false };
bool segment_righttop[10]    = { true,  true,  true,  true,  true,  false, false, true,  true, true  };
bool segment_rightbottom[10] = { true,  true,  false, true,  true,  true,  true,  true,  true, true  };

void initdiscselector()
{
  int i;

  // init input buttons
  for (int i=0; i<4; i++)
  {   pinMode(A0+i, INPUT);
      prevbuttonstate[i] = HIGH;
  }
  
  // init visible digit values and toggle register
  digit0value = 0;
  digit1value = 0;
  activedigit = 0;
  activitylight = 0;
  
  // digit selectors are active high (turn off everything at begin)
  pinMode(11, OUTPUT);
  digitalWrite (11, LOW);
  pinMode(12, OUTPUT);
  digitalWrite (12, LOW);  
  // individual digit segments are active low (turn off everything at begin)
  for (i=3; i<=10; i++)
  {    
    pinMode(i, OUTPUT);
    digitalWrite (i, HIGH);
  }
  
  // start timer
  Timer1.initialize(5000);     // toggle with 100 Hz   
  Timer1.attachInterrupt(polldiscselector);    
}


int getdiskselectorvalue()
{
  return digit0value + digit1value*10;  
}

int setactivitylight()
{
    activitylight = 10;  
}

void polldiscselector()   // interrupt service routine (must not take much time)
{
  // --- query button changes ---
  int i;
  for (i=0; i<4; i++)
  {
      byte s = digitalRead(A0+i);
      if (s!=prevbuttonstate[i])
      {
        prevbuttonstate[i]=s;
        if (s==LOW)
        {   
            // modify digits without needing to do divisions (must be fast)
            switch (i)
            {  case 0: digit1value = digit1value<9 ? digit1value+1 : 0;
                       break;
               case 1: digit1value = digit1value>0 ? digit1value-1 : 9;
                       break;
               case 2: if (digit0value<9)
                       {  digit0value++;
                       }
                       else 
                       {  digit0value=0;
                          digit1value = digit1value<9 ? digit1value+1 : 0;
                       }
                       break;
               case 3: if (digit0value>0)
                       {  digit0value--;
                       }
                       else
                       {
                         digit0value = 9;
                         digit1value = digit1value>0 ? digit1value-1 : 9;
                       }
                       break;
            }
        }
      }
  } 

  // --- count down activity light duration
  if (activitylight>0)
  {
     activitylight--;
  }
  
  // --- display digits alternatingly ----
  // turn off previously active digit
  digitalWrite (11, LOW);
  digitalWrite (12, LOW);
  
  // switch to other digit
  activedigit = 1-activedigit;
  
  // turn on/off digit segments as needed (pin assignment is very arbitrary)
  if (activedigit==0)
  {
     byte v = digit0value;
     digitalWrite (3, segment_top[v] ? LOW : HIGH);
     digitalWrite (6, segment_middle[v] ? LOW : HIGH);
     digitalWrite (7, segment_bottom[v] ? LOW : HIGH);
     digitalWrite (5, segment_lefttop[v] ? LOW : HIGH);  
     digitalWrite (9, segment_leftbottom[v] ? LOW : HIGH);
     digitalWrite (10, segment_righttop[v] ? LOW : HIGH);  
     digitalWrite (8, segment_rightbottom[v] ? LOW : HIGH);
     digitalWrite (4, activitylight>0 ? LOW:HIGH);   // the DOT is used to show activity 
  
     digitalWrite (12, HIGH);  // turn on digit 0
   }
   else
   {
     byte v = digit1value;
     digitalWrite (3, segment_top[v] ? LOW : HIGH);
     digitalWrite (7, segment_middle[v] ? LOW : HIGH);
     digitalWrite (4, segment_bottom[v] ? LOW : HIGH);
     digitalWrite (10, segment_lefttop[v] ? LOW : HIGH);  
     digitalWrite (8, segment_leftbottom[v] ? LOW : HIGH);
     digitalWrite (5, segment_righttop[v] ? LOW : HIGH);  
     digitalWrite (6, segment_rightbottom[v] ? LOW : HIGH);
     digitalWrite (9, HIGH);         // DOT is unused

     digitalWrite (11, HIGH);  // turn on digit 1
   }
}


// ---------------------- DISK FILE HANDLING  -----------------------

bool didinitsd = false;

File discfile;  
unsigned int discsize;         // size in sectors
bool discreadonly;
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

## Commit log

2015-08-21 Initial check-in
    [SIO2SD.brd]
2015-08-21 extended readme and fixed board layout
2015-08-21 moved code, fixed bugs
    [AtariSIO2SD.ino]
2016-09-06 Mini floppy device
    Board design and adapted arduino sketch (supports large and mini boards)
    [Mini1050.brd]
2016-09-09 changed button assignment for mini1080
    [TopLayer1050.brd]
2016-09-10 Key repeat for disk change buttons.
2017-03-15 Breadboard version
    Cleaned up the code a bit, removed support for first board design.
    [SIO2SD.brd]
2018-03-17 Disk folder reorganization
    To prepare for future changes in the button interface, I have flattened
    and restructured the floppy directory and renamed it to ATARI to match
    the folder name on the SDCARD
2018-03-18 Emulate formatting of single and medium density floppies
    [sio2sd.kicad_pcb, sio2sd.sch]
2018-04-06 Error state if SDcard not present at startup
    [AtariSIO2SD.ino]
2018-04-07 Tweak program to start up fast again
    Instead of initializing SDcard before everything else, defer this until
    actual disk access is done. This is necessary to make the SIO2SD device
    respond immediately to the booting atari.
2018-04-08 Start designing PCB for small SIO2SD variant
    [sio2sd.kicad_pcb]
2018-04-14 Single board device design
    [sio2sd.kicad_pcb, sio2sd.sch]
2018-04-15 Change reset circuit, layout fixes
    [sio2sd.kicad_pcb, sio2sd.sch]
2018-04-15 Small layout fixes, Gerber files
    [sio2sd-B.Cu.gbr, sio2sd-B.Mask.gbr, sio2sd-B.SilkS.gbr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]
2018-04-22 Allow multi-slave configuration
    By inserting a diode into TX -> Data In, the device can emulate an open
    collector to not interfer with other devices on the same bus.
    [sio2sd-B.Cu.gbr, sio2sd-B.Mask.gbr, sio2sd-B.SilkS.gbr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]
2020-08-01 Bring design files to new KiCAD version. Create gerber files.
    [sio2sd-2020-07-29-08-33-40.sch, sio2sd.kicad_pcb, sio2sd.sch]
2020-08-27 3D-printed case, more images.
    [atari1050_sd_final.blend, buttons.stl, frontplate.stl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]
